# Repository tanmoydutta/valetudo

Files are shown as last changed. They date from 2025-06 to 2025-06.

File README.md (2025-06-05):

# Valetudo, a BLE enabled ePaper fridge magnet module
It is a Module to show information on a 1.54" 200 x 200 pixel Black and White ePaper display. Together with a suitable 3D printed housing it can be used as a fridge magnet to display useful information. 

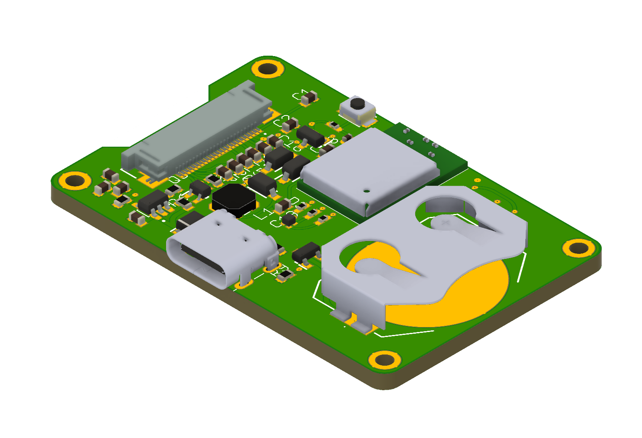
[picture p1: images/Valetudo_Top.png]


Below is the built module running a test sketch -


This is an OSHWA certified hardware - 
<p align="center">
  <a href="https://certification.oshwa.org/nl000029.html">
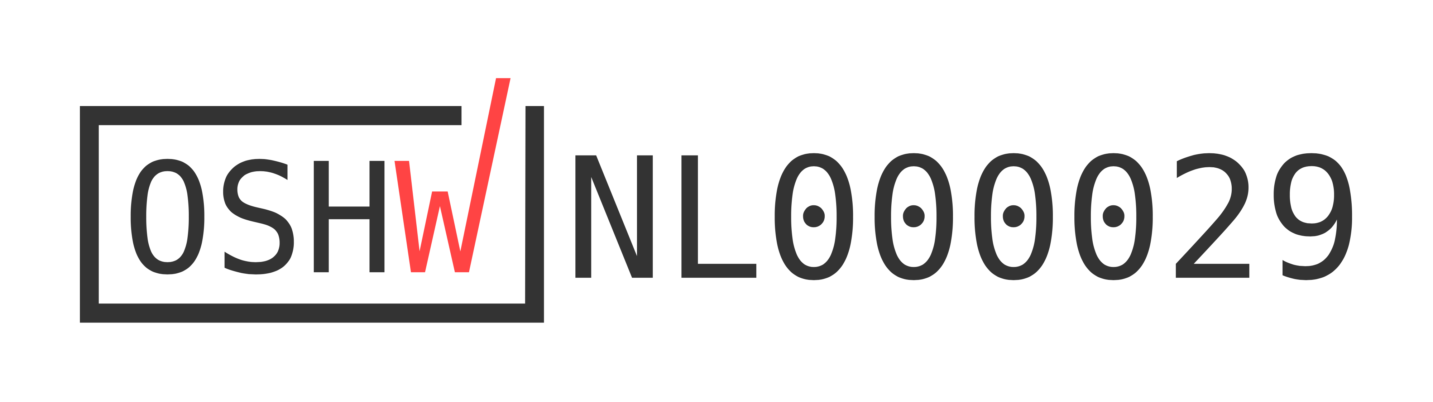
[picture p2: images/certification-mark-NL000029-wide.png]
OSHWA OSHWA Certification
    
  </a>
</p>



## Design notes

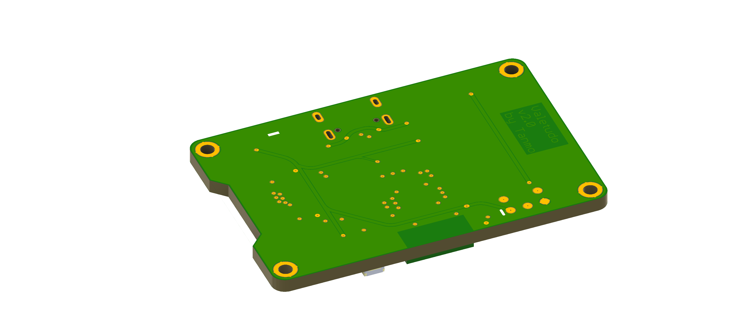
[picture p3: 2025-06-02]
images/Valetudo_bottom.png

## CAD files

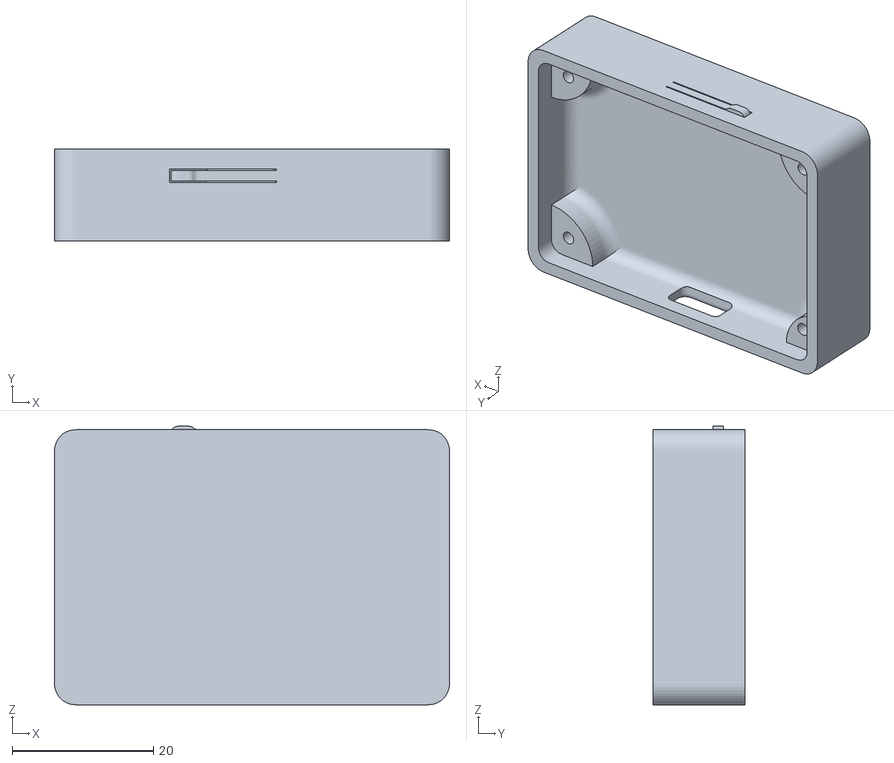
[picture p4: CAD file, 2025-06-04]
3D_models_enclosure/Bottom_Alt.stl
56.0 x 13.0 x 39.5

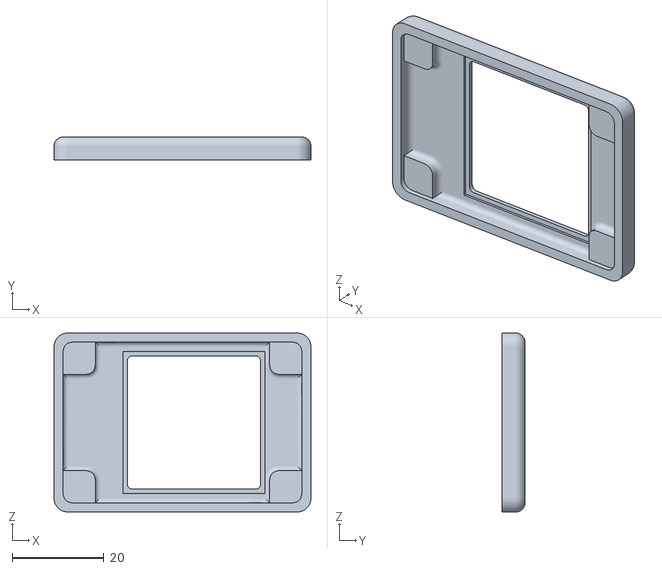
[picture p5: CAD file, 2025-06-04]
3D_models_enclosure/Top_Alt.stl
56.0 x 5.00 x 39.0

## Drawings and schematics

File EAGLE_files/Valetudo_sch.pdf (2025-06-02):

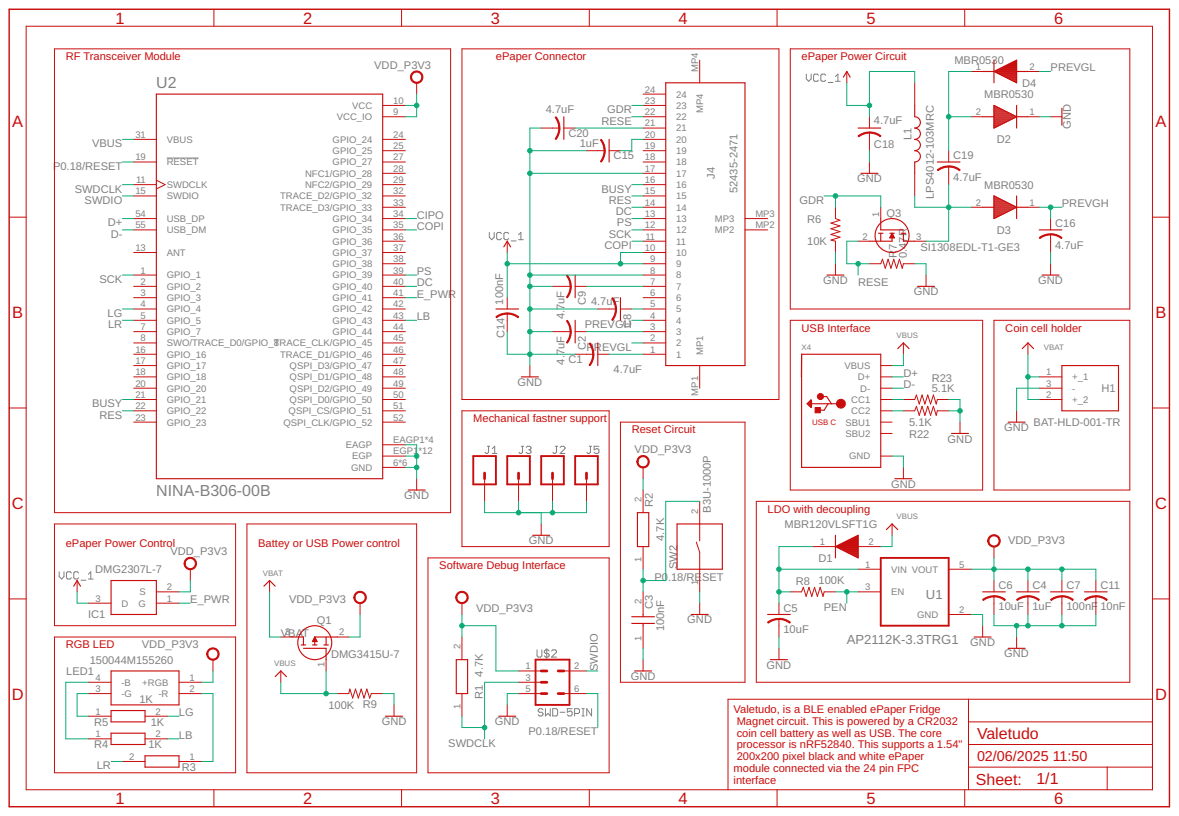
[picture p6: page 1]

Battey or USB Power control

Valetudo, is a BLE enabled ePaper Fridge Magnet circuit. This is powered by a CR2032 coin cell battery as well as USB. The core processor is nRF52840. This supports a 1.54" 200x200 pixel black and white ePaper module connected via the 24 pin FPC interface

Sheet: 1/1

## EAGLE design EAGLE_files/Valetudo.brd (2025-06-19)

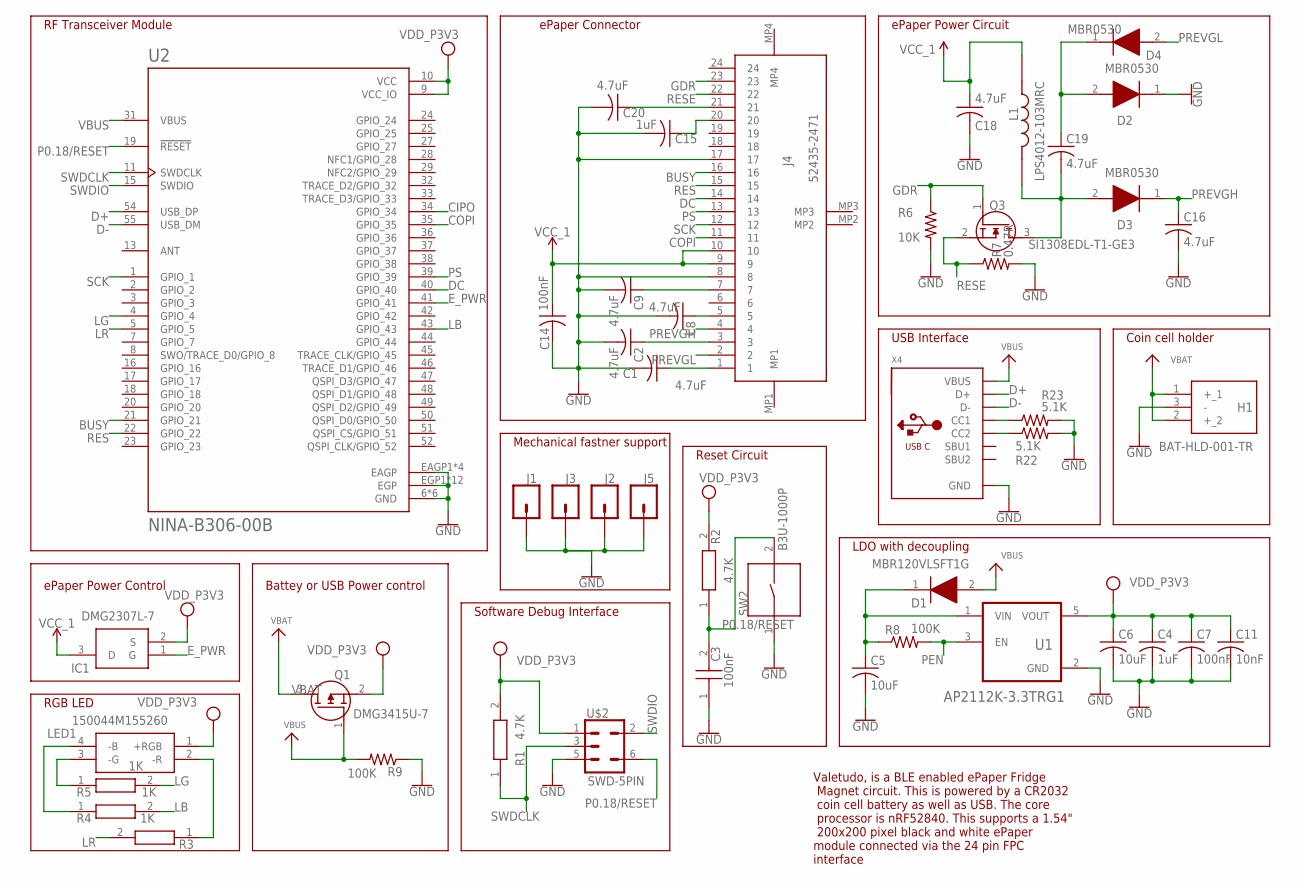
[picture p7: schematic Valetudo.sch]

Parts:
C1, C2, C8, C9, C16, C18, C19, C20: 4.7uF; C0402
C3: 100nF; CAPC1005X55N
C4, C15: 1uF; C0402
C5, C6: 10uF; C0402
C7, C14: 100nF; C0402
C11: 10nF; C0402
D1: MBR120VLSFT1G; SODFL3616X98N
D2, D3, D4: MBR0530; SOD3716X135N
H1: BAT-HLD-001-TR; BATHLD001TR
IC1: DMG2307L-7; SOT96P240X110-3N
J1, J2, J3, J5: CONN_01PTH_2MM; 1X01_2MM
J4: 52435-2471; 524352471
L1: LPS4012-103MRC; IND_LPS4012-103MRC
LED1: 150044M155260
Q1: DMG3415U-7; SOT96P240X100-3N
Q3: SI1308EDL-T1-GE3; SOT65P210X110-3N
R1, R2: 4.7K; RESC1005X40N
R3, R4, R5: 1K; RESC1005X40N
R6: 10K; R0402
R7: 0.47R; R0402
R8, R9: 100K; R0402
R22, R23: 5.1K; R0402
SW2: B3U-1000P; SW_B3U-1000P
U1: AP2112K-3.3TRG1; SOT95P285X140-5N
U2: NINA-B306-00B; XCVR_NINA-B306-00B
U$2: SWD-5PIN; PAD_05_03X2_TP_NO4
X4: MICROBUILDER_USB_C; MICROBUILDER_USB_C_CUSB31-CFM2AX-01-X

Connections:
BUSY: J4.16, U2.21 (GPIO_21)
CIPO: U2.34 (GPIO_34)
COPI: J4.11, U2.35 (GPIO_35)
D+: U2.54 (USB_DP), X4.A6 (D+), X4.B6 (D+)
D-: U2.55 (USB_DM), X4.A7 (D-), X4.B7 (D-)
DC: J4.14, U2.40 (GPIO_40)
E_PWR: IC1.1 (G), U2.41 (GPIO_41)
GDR: J4.23, Q3.1 (G), R6.1
GND: C1.2, C2.2, C3.1, C4.2, C5.2, C6.2, C7.2, C8.2, C9.2, C11.2, C14.2, C15.2, C16.2, C18.2, C20.2, D2.1 (K), H1.3 (-), J1.1, J2.1, J3.1, J4.8, J4.17, J5.1, R6.2, R7.2, R9.1, R22.2, R23.2, SW2.1, U1.2 (GND), U2.6 (GND), U2.12 (GND), U2.14 (GND), U2.26 (GND), U2.30 (GND), U2.53 (GND), U2.EAGP1 (EAGP), U2.EAGP2 (EAGP), U2.EAGP3 (EAGP), U2.EAGP4 (EAGP), U2.EGP1 (EGP), U2.EGP2 (EGP), U2.EGP3 (EGP), U2.EGP4 (EGP), U2.EGP5 (EGP), U2.EGP6 (EGP), U2.EGP7 (EGP), U2.EGP8 (EGP), U2.EGP9 (EGP), U2.EGP10 (EGP), U2.EGP11 (EGP), U2.EGP12 (EGP), U$2.5, X4.A1B12 (GND), X4.B1A12 (GND)
LB: R4.2, U2.43 (GPIO_43)
LG: R5.2, U2.4 (GPIO_4)
LR: R3.2, U2.5 (GPIO_5)
unnamed: LED1.4 (-B), R4.1
unnamed: LED1.3 (-G), R5.1
unnamed: LED1.2 (-R), R3.1
unnamed: C1.1, J4.1
unnamed: C19.1, D2.2 (A), D4.1 (K)
unnamed: R22.1, X4.B5 (CC2)
unnamed: C2.1, J4.3
unnamed: R23.1, X4.A5 (CC1)
unnamed: C5.1, D1.1 (K), R8.1, U1.1 (VIN)
unnamed: C19.2, D3.2 (A), L1.2, Q3.3 (D)
unnamed: C8.1, J4.5
unnamed: C9.1, J4.7
unnamed: C15.1, J4.20
unnamed: C20.1, J4.21
P0.18/RESET: C3.2, R2.1, SW2.2, U2.19 (!RESET), U$2.6
PEN: R8.2, U1.3 (EN)
PREVGH: C16.1, D3.1 (K), J4.4
PREVGL: D4.2 (A), J4.2
PS: J4.13, U2.39 (GPIO_39)
RES: J4.15, U2.22 (GPIO_22)
RESE: J4.22, Q3.2 (S), R7.1
SCK: J4.12, U2.1 (GPIO_1)
SWDCLK: R1.1, U2.11 (SWDCLK), U$2.3
SWDIO: U2.15 (SWDIO), U$2.2
VBAT: H1.1 (+_1), H1.2 (+_2), Q1.3 (D)
VBUS: D1.2 (A), Q1.1 (G), R9.2, U2.31 (VBUS), X4.A4B9 (VBUS), X4.B4A9 (VBUS)
VCC: C4.1, C6.1, C7.1, C11.1, IC1.2 (S), LED1.1 (+RGB), Q1.2 (S), R1.2, R2.2, U1.5 (VOUT), U2.9 (VCC_IO), U2.10 (VCC), U$2.1
VCC_1: C14.1, C18.1, IC1.3 (D), J4.9, J4.10, L1.1

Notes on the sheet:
Battey or USB Power control
RF Transceiver Module
LDO with decoupling
Reset Circuit
USB Interface
Software Debug Interface
Valetudo, is a BLE enabled ePaper Fridge Magnet circuit. This is powered by a CR2032 coin cell battery as well as USB. The core processor is nRF52840. This supports a 1.54" 200x200 pixel black and white ePaper module connected via the 24 pin FPC interface
RGB LED
ePaper Power Circuit
Mechanical fastner support
ePaper Connector
Coin cell holder
ePaper Power Control

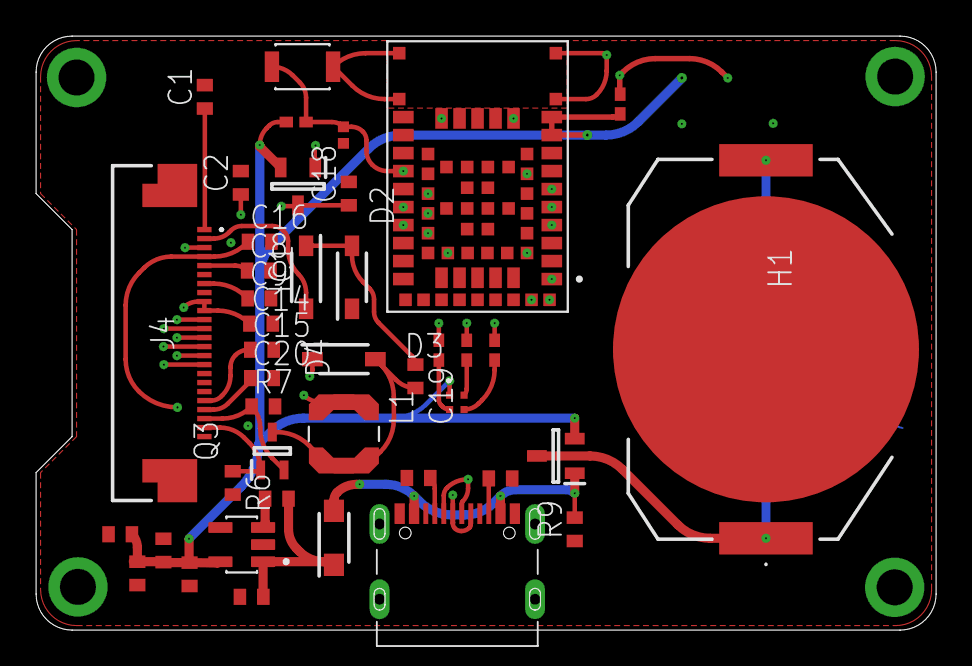
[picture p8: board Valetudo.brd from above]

Board: 6 copper layers, 50.0 x 33.0 mm, 47 parts (1 on the bottom side), 39 nets.

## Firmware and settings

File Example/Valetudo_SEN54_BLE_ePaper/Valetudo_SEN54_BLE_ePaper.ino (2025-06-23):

#include <ArduinoBLE.h>
#define ENABLE_GxEPD2_GFX 0

#include <GxEPD2_BW.h>

#include <Fonts/FreeMonoBold9pt7b.h>
#include <Fonts/FreeMonoBold12pt7b.h>


GxEPD2_BW<GxEPD2_154_M09, GxEPD2_154_M09::HEIGHT> display(GxEPD2_154_M09(/*CS=D8*/ D2, /*DC=D3*/ D4, /*RST=D4*/ D5, /*BUSY=D2*/ D3)); // GDEW0154M09 200x200, JD79653A

// UUIDs used by the ESP32 BLE Server
const char* SERVICE_UUID = "d0000000-0000-1000-8000-00805f9b34fb";
const char* TEMP_UUID    = "2A6E";  // Temperature
const char* HUM_UUID     = "2A6F";  // Humidity
const char* VOC_UUID     = "d0000004-0000-1000-8000-00805f9b34fb";
const char* NOX_UUID     = "d0000005-0000-1000-8000-00805f9b34fb";
const char* PM25_UUID    = "2BD3";  // PM2.5

BLEDevice peripheral;
BLECharacteristic tempChar, humChar, vocChar, noxChar, pm25Char;

float decodeSFloat(const uint8_t* data) {
  uint16_t raw = data[1] << 8 | data[0];
  int16_t mantissa = raw & 0x0FFF;
  int8_t exponent = (raw >> 12) & 0x0F;
  if (mantissa & 0x0800) mantissa |= 0xF000; // sign extend
  return mantissa * pow(10, exponent);
}

bool connectToServer() {
  Serial.println("Scanning for BLE server...");

  BLE.scanForUuid(SERVICE_UUID);  // << simplified scan with filter

  BLEDevice dev;
  unsigned long timeout = millis() + 10000;
  while (millis() < timeout) {
    dev = BLE.available();
    if (dev) break;
  }
  BLE.stopScan();

  if (!dev) {
    Serial.println("No BLE server found.");
    return false;
  }

  Serial.print("Connecting to: ");
  Serial.println(dev.address());

  if (!dev.connect()) {
    Serial.println("Connection failed.");
    return false;
  }

  if (!dev.discoverAttributes()) {
    Serial.println("Service discovery failed.");
    dev.disconnect();
    return false;
  }

  peripheral = dev;

  tempChar  = peripheral.characteristic(TEMP_UUID);
  humChar   = peripheral.characteristic(HUM_UUID);
  vocChar   = peripheral.characteristic(VOC_UUID);
  noxChar   = peripheral.characteristic(NOX_UUID);
  pm25Char  = peripheral.characteristic(PM25_UUID);

  if (!(tempChar && humChar && vocChar && noxChar && pm25Char)) {
    Serial.println("One or more characteristics not found.");
    peripheral.disconnect();
    return false;
  }

  Serial.println("Connected to server.");
  return true;
}

void readAndPrint(BLECharacteristic& ch, const char* label) {
  uint8_t data[2];
  if (ch.readValue(data, 2)) {
    float value = decodeSFloat(data);
    Serial.print(label);
    Serial.print(": ");
    Serial.println(value);
    displayData(value);
  } else {
    Serial.print(label);
    Serial.println(": Read failed");
  }
}

void setup() {
  Serial.begin(115200);
  //while (!Serial);
  pinMode(D6, OUTPUT);
  digitalWrite(D6, LOW);

  display.init(115200);
  ble_init();
}

void loop() {
  ble_init();
  if (!peripheral || !peripheral.connected()) {
    if (!connectToServer()) {
      delay(90000);
      return;
    }
  }

  //readAndPrint(tempChar,  "Temperature");
  //readAndPrint(humChar,   "Humidity");
  //readAndPrint(vocChar,   "VOC Index");
  //readAndPrint(noxChar,   "NOx Index");
  readAndPrint(pm25Char,  "PM2.5");

  BLE.disconnect();
  BLE.end();
  Serial.println("---");
  delay(90000);
  delay(90000);
}

void displayData(float pm25)
{
  //Serial.println("helloWorld");
  display.setRotation(1);
  display.setFont(&FreeMonoBold12pt7b);
  display.setTextSize(2);
  if (display.epd2.WIDTH < 104) display.setFont(0);
  display.setTextColor(GxEPD_BLACK);
  int16_t tbx, tby; uint16_t tbw, tbh;
  //display.getTextBounds(HelloWorld, 0, 0, &tbx, &tby, &tbw, &tbh);
  // center bounding box by transposition of origin:
  //uint16_t x = ((display.width() - tbw) / 2) - tbx;
  //uint16_t y = ((display.height() - tbh) / 2) - tby;
  display.setFullWindow();
  display.firstPage();
  do
  {
    display.fillScreen(GxEPD_WHITE);
    display.setCursor(30, 60);
    display.print("PM2.5");
    display.setCursor(30, 120);
    display.print(pm25);
  }
  while (display.nextPage());
  //Serial.println("helloWorld done");
}

void ble_init() {
  if (!BLE.begin()) {
    Serial.println("Failed to initialize BLE!");
    while (1);
  }

  BLE.setLocalName("NanoClient");
  BLE.setDeviceName("NanoClient");

  if (!connectToServer()) {
    Serial.println("Retrying in loop...");
  }

}

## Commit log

2025-06-02 Adding new files
    [Valetudo.brd, Valetudo.sch]
2025-06-04 3D files added
    [Bottom_Alt.stl, Top_Alt.stl]
2025-06-19 Updates to board file
    [Valetudo.brd, Valetudo.sch]
2025-06-23 Adding a sample sketch

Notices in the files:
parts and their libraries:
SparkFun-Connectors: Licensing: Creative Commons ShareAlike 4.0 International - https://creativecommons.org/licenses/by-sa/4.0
